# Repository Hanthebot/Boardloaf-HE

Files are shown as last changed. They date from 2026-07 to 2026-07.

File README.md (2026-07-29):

# Boardloaf-HE

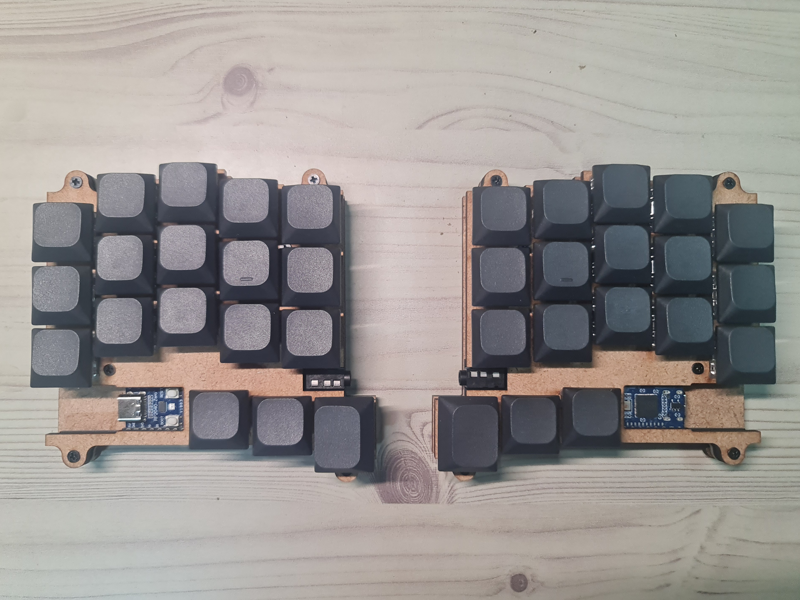
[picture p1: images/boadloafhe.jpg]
boardloafhe


Hall-effect variant of [Yuburoll's Boardloaf](https://github.com/yuburoll/Boardloaf), a 36-key split keyboard.

Wooting compatible, reversible, under 100mm pcb with qmk/vial support.

Based on Boardloaf and strongly inspired by [TrueStrike42](https://github.com/byungyoonc/TrueStrike42)

## Preparation
- Pricing: PCB based on JLCPCB / components based on Taobao (shipping to South Korea)
- Shipping fee not included, but PCB can be shipped with $1.5 option and Taobao delivery fee is acceptable for price gap
- Assumes you only want to build one (which makes cost higher)

### Board
| Component | Qty | Price/unit | Price |
| --- | --- | --- | ----- |
| PCB | 2 | $2/5 pcs | $2 |
| SOT-23 SS49E | 36  | ¥0.31/1 pc ~= $0.05 | $2 |
| SOIC-16 74HC4051(D)  | 6 | ¥0.74/1 pc ~= $0.11 | $0.7  |
| 0805 0.1uf capacitor | 42  | ¥2.5/50 pcs ~= $0.4 | $0.4  |
| PJ320A TRRS socket | 2 | ¥8/100 pcs ~= $1.2  | $1.2  |
| RP2040 Zero | 2 | ¥7.3/1 pc ~= $1.1 | $2.2  |
- For capacitor, 0.1~1uf should be fine
- And obviously, USB-C cable of your choice (with machine) and TRS/TRRS cable of your choice
- Board cost: $9 or more

### Case
- Option A: 3D printed case (from yuburoll's repo)
- Option B: Cheap plate cut
  - requires heat insert and standoff
  - 3T mdf panel of A4 size can fit 2x top & bottom plate
      - and costs about $1

| Component | Qty | Price/unit | Price |
| --- | --- | --- | ----- |
| M2 screw 6mm | 16  | ¥4/500 pcs ~= $0.6 | $0.6  |
| M2 heat insert 3*3 | 16  | ¥4.9/100 pcs ~= $0.7  | $0.7  |
| M2 standoff 7mm + 3mm head | 16  | ¥2.31/50 pcs ~= $0.35 | $0.35 |
- Flathead screw was used
- Standoff can be shorter or longer - but I recommend 5mm at least
- Case cost: $3 or more

### Switches
| Component | Qty | Price/unit | Price |
| --- | --- | --- | ----- |
| Wooting compatible magnetic switch | 36  | ¥36/40 pcs ~= $5.3 | $5.3  |
- I personally chose Everglide Sticky Rice, as it was the cheapest I could find.
- While those without side pins should be fine, I'd use one with side pins so that they fix better
- Firmware fix may be required to use the opposite polarity
- Switch cost: $6 or more

With these things combined, you can get your own HE keyboard in about $12 excluding cables and switches.

## [Build guide](GUIDE.md)

## Features
- Supports both APC and rapid trigger
- Cheap, simple, and working
- 3 multiplexor on each side, scanning 6 keys per mux

## Improvements to be done
- [ ] Support analog mousekey
- [ ] Switch to full duplex / TRRS communication
- [x] Make SOT-23 pad larger, thus easier to solder
- [ ] ~~Switch to blackpill mcu for better ADC (not in this repo)~~

## Remarks
- Initial config recommendation: 30% / 20% / 20% / 10% / 10% / 20% (APC act / release; RT init dead / act offset / release offset / bottom dead)
- Documentation
  - Further documentation in progress
  - Plate KiCad file to be uploaded
  - Images to be added
- Case
  - PCB outline and holes are the same as original Boardloaf, thus all housing are compatible
  - I used cheap 3T mdf for housing, with bumpons. Works fine for me
- Random
  - PCB schematics are almost directly from TrueStrike42
  - If your board does not work, it's likely soldering issue. Try cleaning the board well and solder again
  - I think it's a good start on implementing random idea for HE keyboard

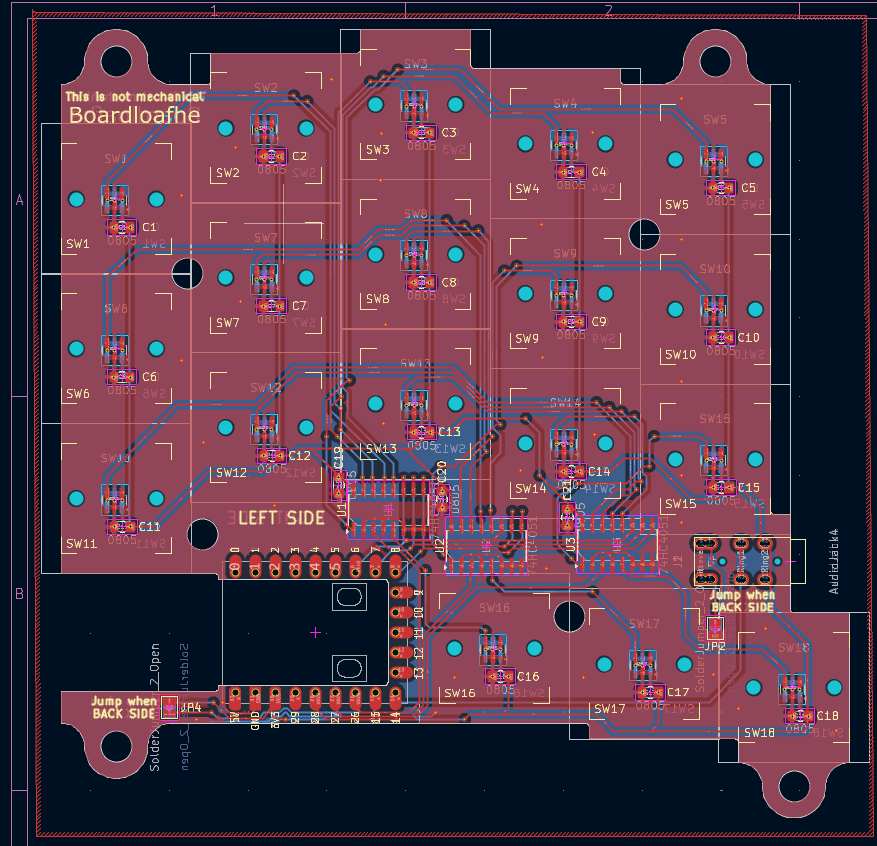
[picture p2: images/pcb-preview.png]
PCB


## Licenses
All code under firmware folder follows GPL v3.

Webapp is MIT license.

CC BY-SA 4.0 license for all hardware / design: inherited from Boardloaf

## Disclaimer
Webapp and firmware modification were vibe coded.
I checked it working.

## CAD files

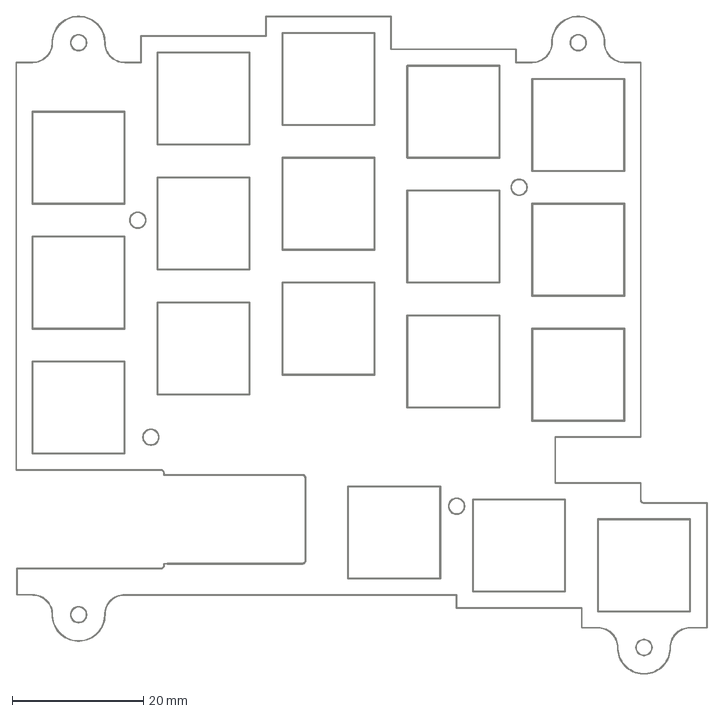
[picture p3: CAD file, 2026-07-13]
plate/top-plate.dxf
105.1 x 100.1 mm

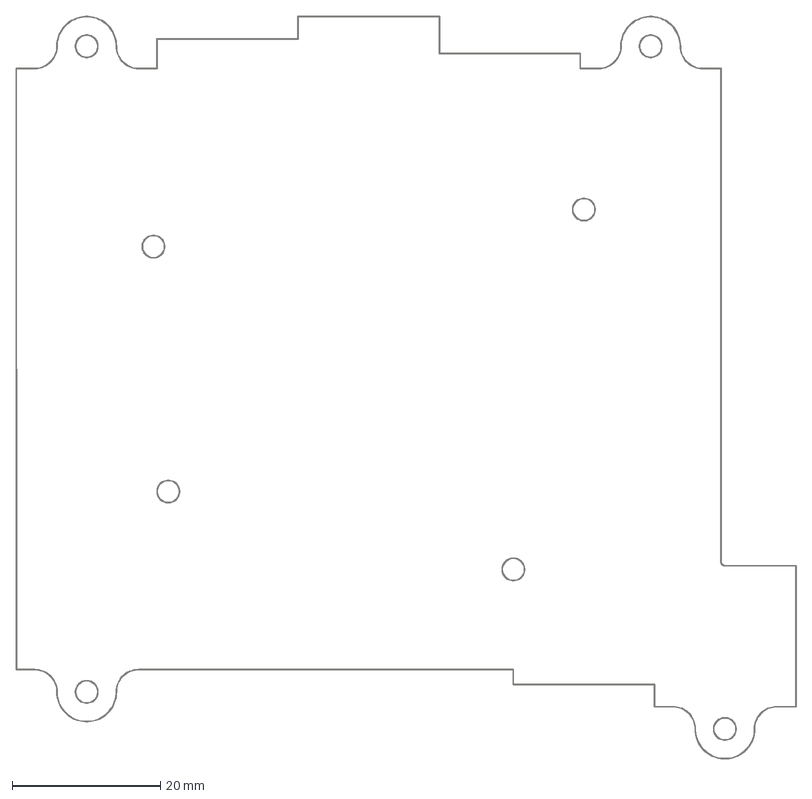
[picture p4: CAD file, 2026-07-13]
plate/bottom-plate.dxf
105.1 x 100.1 mm

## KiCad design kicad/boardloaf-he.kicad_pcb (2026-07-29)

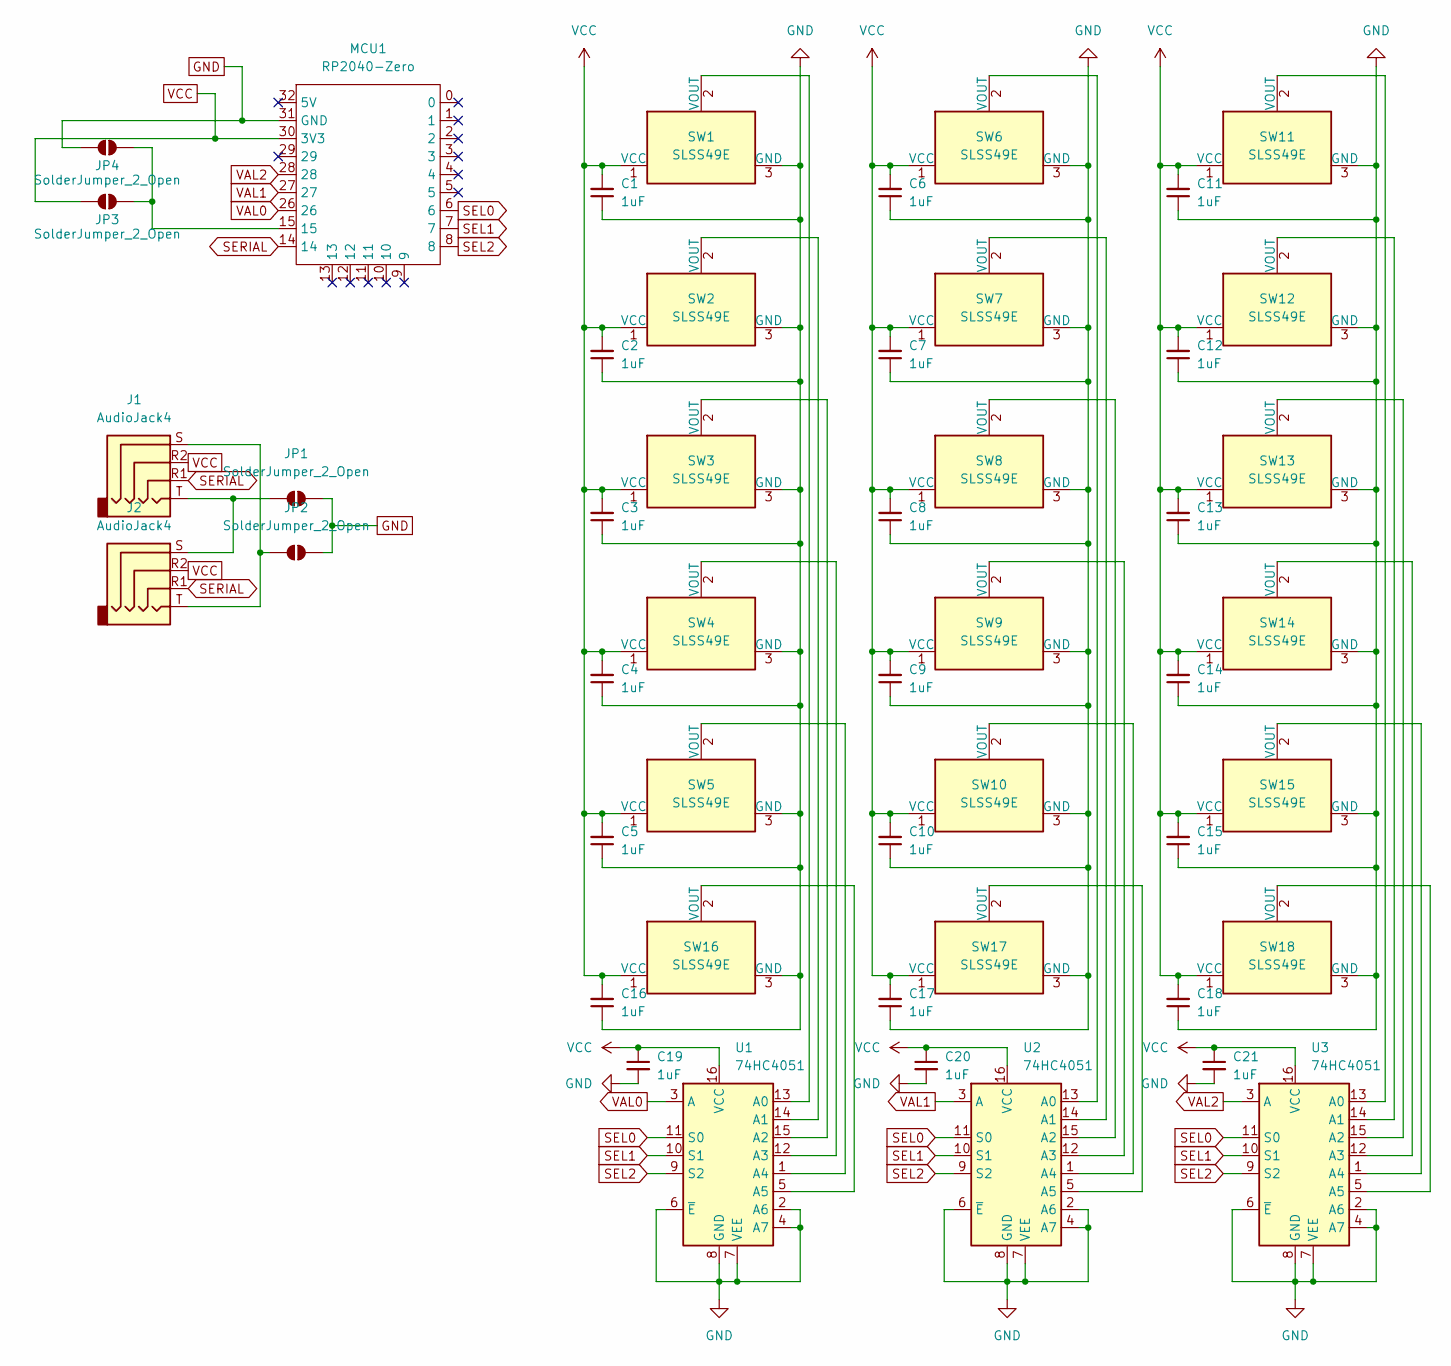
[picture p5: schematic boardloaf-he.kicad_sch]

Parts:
C1, C2, C3, C4, C5, C6, C7, C8, C9, C10, C11, C12, C13, C14, C15, C16, C17, C18, C19, C20, C21: 1uF; C_0805_2012Metric_Pad1.18x1.45mm_HandSolder
J1, J2: AudioJack4; TRRS-PJ-320A_PIN
JP1, JP2, JP3, JP4: SolderJumper_2_Open; SolderJumper-2_P1.3mm_Open_TrianglePad1.0x1.5mm
MCU1: RP2040-Zero; RP2040-Zero-RESIZED
SW1, SW2, SW3, SW4, SW5, SW6, SW7, SW8, SW9, SW10, SW11, SW12, SW13, SW14, SW15, SW16, SW17, SW18: SLSS49E; HE-Switch-1U
U1, U2, U3: 74HC4051; SOIC-16_3.9x9.9mm_P1.27mm

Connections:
GND: C1.1, C2.1, C3.1, C4.1, C5.1, C6.1, C7.1, C8.1, C9.1, C10.1, C11.1, C12.1, C13.1, C14.1, C15.1, C16.1, C17.1, C18.1, C19.2, C20.2, C21.2, JP1.2 (B), JP2.2 (B), JP4.1 (A), MCU1.31 (GND), SW1.3 (GND), SW2.3 (GND), SW3.3 (GND), SW4.3 (GND), SW5.3 (GND), SW6.3 (GND), SW7.3 (GND), SW8.3 (GND), SW9.3 (GND), SW10.3 (GND), SW11.3 (GND), SW12.3 (GND), SW13.3 (GND), SW14.3 (GND), SW15.3 (GND), SW16.3 (GND), SW17.3 (GND), SW18.3 (GND), U1.2 (A6), U1.4 (A7), U1.6 (~E), U1.7 (VEE), U1.8 (GND), U2.2 (A6), U2.4 (A7), U2.6 (~E), U2.7 (VEE), U2.8 (GND), U3.2 (A6), U3.4 (A7), U3.6 (~E), U3.7 (VEE), U3.8 (GND)
unnamed: J1.T, J2.S, JP1.1 (A)
unnamed: J1.S, J2.T, JP2.1 (A)
unnamed: JP3.2 (B), JP4.2 (B), MCU1.15
unnamed: SW1.2 (VOUT), U1.13 (A0)
unnamed: SW2.2 (VOUT), U1.14 (A1)
unnamed: SW3.2 (VOUT), U1.15 (A2)
unnamed: SW4.2 (VOUT), U1.12 (A3)
unnamed: SW5.2 (VOUT), U1.1 (A4)
unnamed: SW6.2 (VOUT), U2.13 (A0)
unnamed: SW7.2 (VOUT), U2.14 (A1)
unnamed: SW8.2 (VOUT), U2.15 (A2)
unnamed: SW9.2 (VOUT), U2.12 (A3)
unnamed: SW10.2 (VOUT), U2.1 (A4)
unnamed: SW11.2 (VOUT), U3.13 (A0)
unnamed: SW12.2 (VOUT), U3.14 (A1)
unnamed: SW13.2 (VOUT), U3.15 (A2)
unnamed: SW14.2 (VOUT), U3.12 (A3)
unnamed: SW15.2 (VOUT), U3.1 (A4)
unnamed: SW16.2 (VOUT), U1.5 (A5)
unnamed: SW17.2 (VOUT), U2.5 (A5)
unnamed: SW18.2 (VOUT), U3.5 (A5)
SEL0: MCU1.6, U1.11 (S0), U2.11 (S0), U3.11 (S0)
SEL1: MCU1.7, U1.10 (S1), U2.10 (S1), U3.10 (S1)
SEL2: MCU1.8, U1.9 (S2), U2.9 (S2), U3.9 (S2)
SERIAL: J1.R1, J2.R1, MCU1.14
VAL0: MCU1.26, U1.3 (A)
VAL1: MCU1.27, U2.3 (A)
VAL2: MCU1.28, U3.3 (A)
VCC: C1.2, C2.2, C3.2, C4.2, C5.2, C6.2, C7.2, C8.2, C9.2, C10.2, C11.2, C12.2, C13.2, C14.2, C15.2, C16.2, C17.2, C18.2, C19.1, C20.1, C21.1, J1.R2, J2.R2, JP3.1 (A), MCU1.30 (3V3), SW1.1 (VCC), SW2.1 (VCC), SW3.1 (VCC), SW4.1 (VCC), SW5.1 (VCC), SW6.1 (VCC), SW7.1 (VCC), SW8.1 (VCC), SW9.1 (VCC), SW10.1 (VCC), SW11.1 (VCC), SW12.1 (VCC), SW13.1 (VCC), SW14.1 (VCC), SW15.1 (VCC), SW16.1 (VCC), SW17.1 (VCC), SW18.1 (VCC), U1.16 (VCC), U2.16 (VCC), U3.16 (VCC)

Board: 2 copper layers, 49 parts (3 on the bottom side), 30 nets, no tracks yet.

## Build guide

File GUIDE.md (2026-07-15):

# Build guide

Also check out: [Modubu build guide](https://github.com/yuburoll/modubu/blob/main/documents/buildGuide_ko.md) (RP2040 Zero soldering, in Korean)

### Preparation
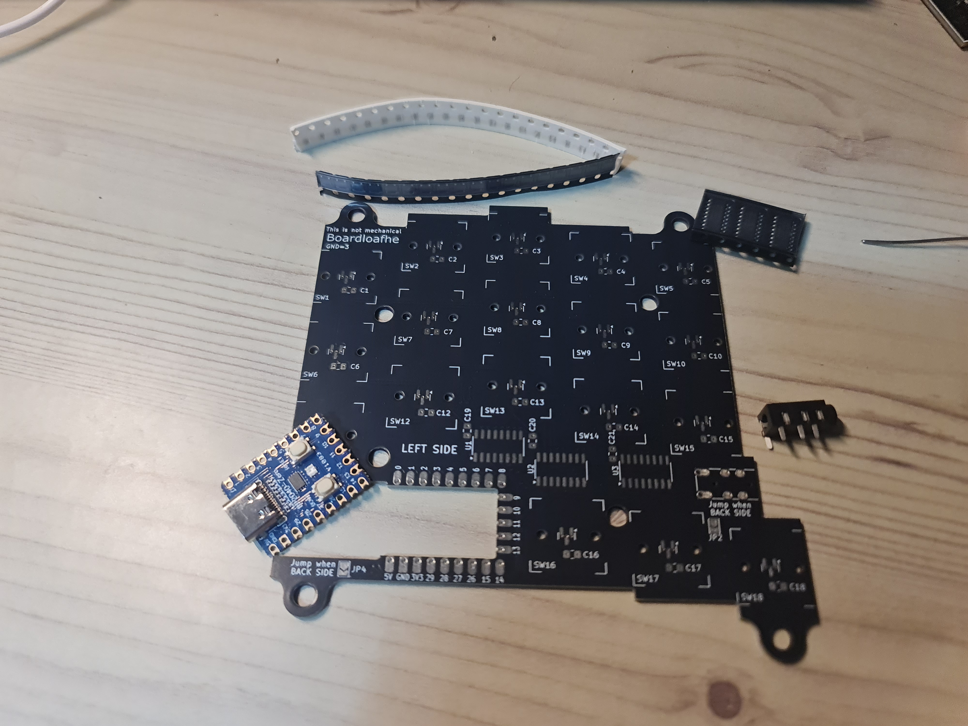
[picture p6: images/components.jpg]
Components


For each half, make sure you have:
- PCB
- RP2040 Zero
- PJ320A TRRS 3.5mm Socket
- SOIC-16 74HC4051 x 3
- SOT-23 SS49E x 36
- 0805 0.1uf capacitor x 42
  - actually optional

Recommended soldering order:
1. 74HC4051
2. SS49E
3. RP2040 Zero
4. PJ320A
5. capacitor

All jumpers: at the back

### 74HC4051
Ensure that the circle mark matches the arrow mark on the PCB!
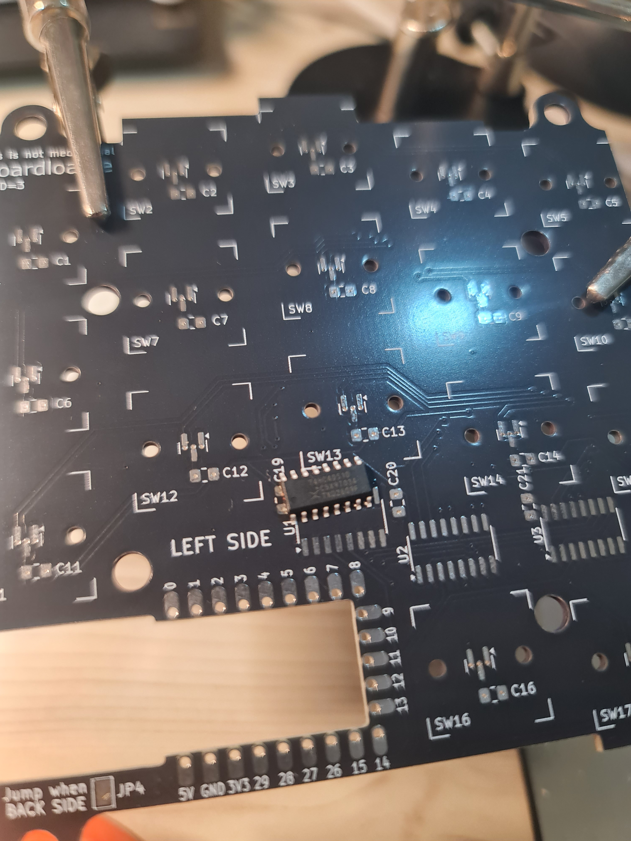
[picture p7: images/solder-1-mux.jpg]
mux-solder-1


As many build guides suggested, apply solder on one of the solder mask, then push the component towards solder while it's molten.

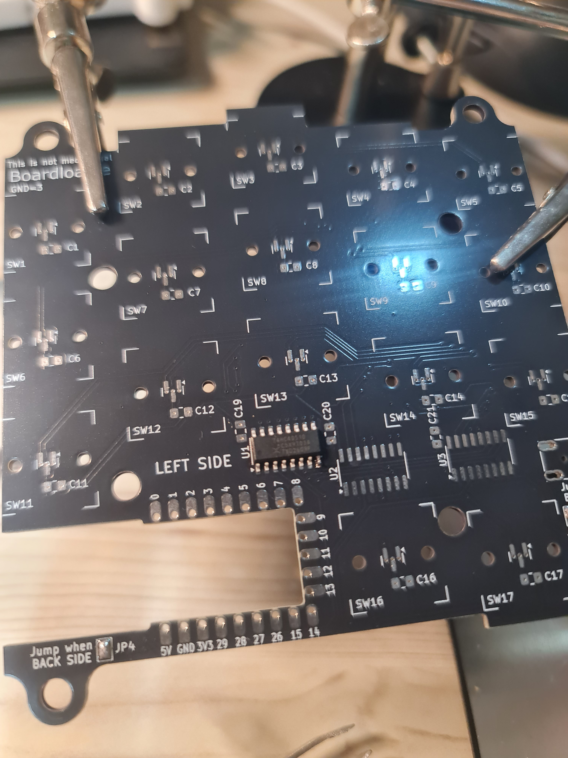
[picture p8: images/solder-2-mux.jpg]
mux-solder-2


Then you may solder the rest. PCB is reversible, but the multiplexor can only lie on single plane.

### SS49E

Like the multiplexor, apply solder on one of the solder mask - I recommend the middle one. Push it, and finish soldering other pins. Just in case, ensure that your sensor has the same pinout as PCB! (it probably will).

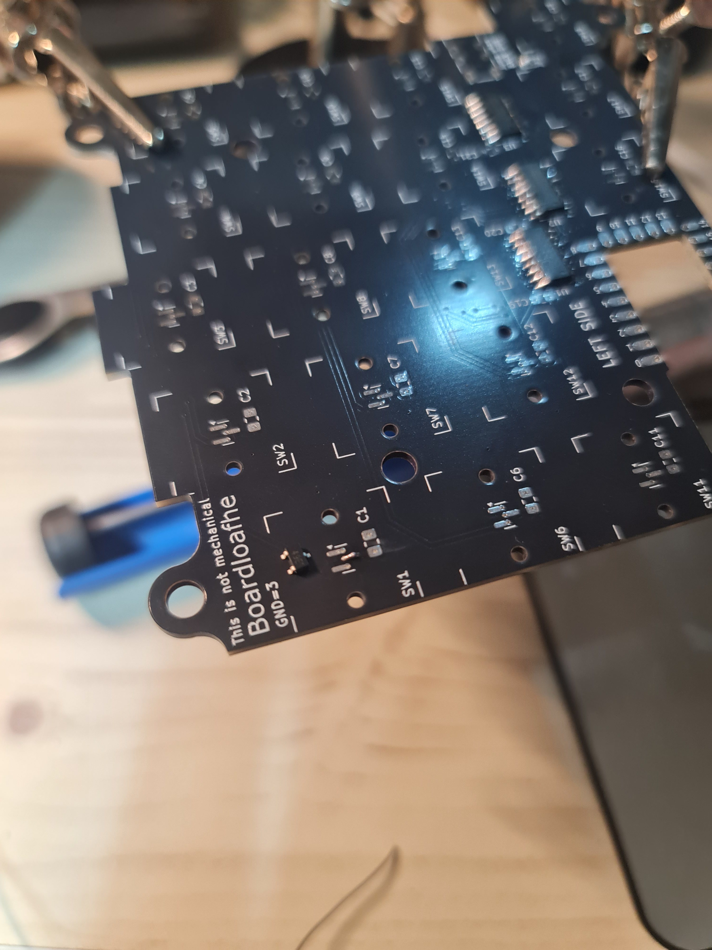
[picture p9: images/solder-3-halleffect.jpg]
halleffect-solder


### RP2040 Zero
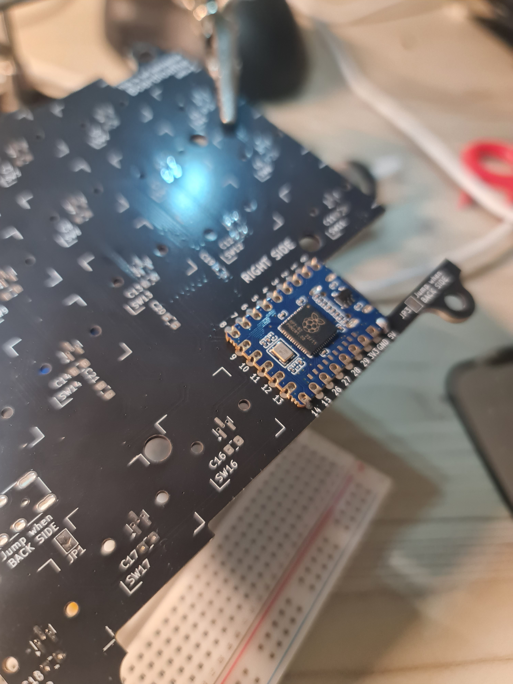
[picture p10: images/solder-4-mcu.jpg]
MCU

Solder in SMD manner, ensuure that the pin number matches the PCB.

USB-C port will be almost on the same plane with the PCB.

Recommendataion: solder one corner or more. Then solder the rest.

### PJ320A
*Just do it*

### Capacitor

Capacitors are to prevent voltage shocks... or so I heard. The keyboard should work properly without it, but let's play safe.

It has no direction.

Like others, apply solder, push, and pull.

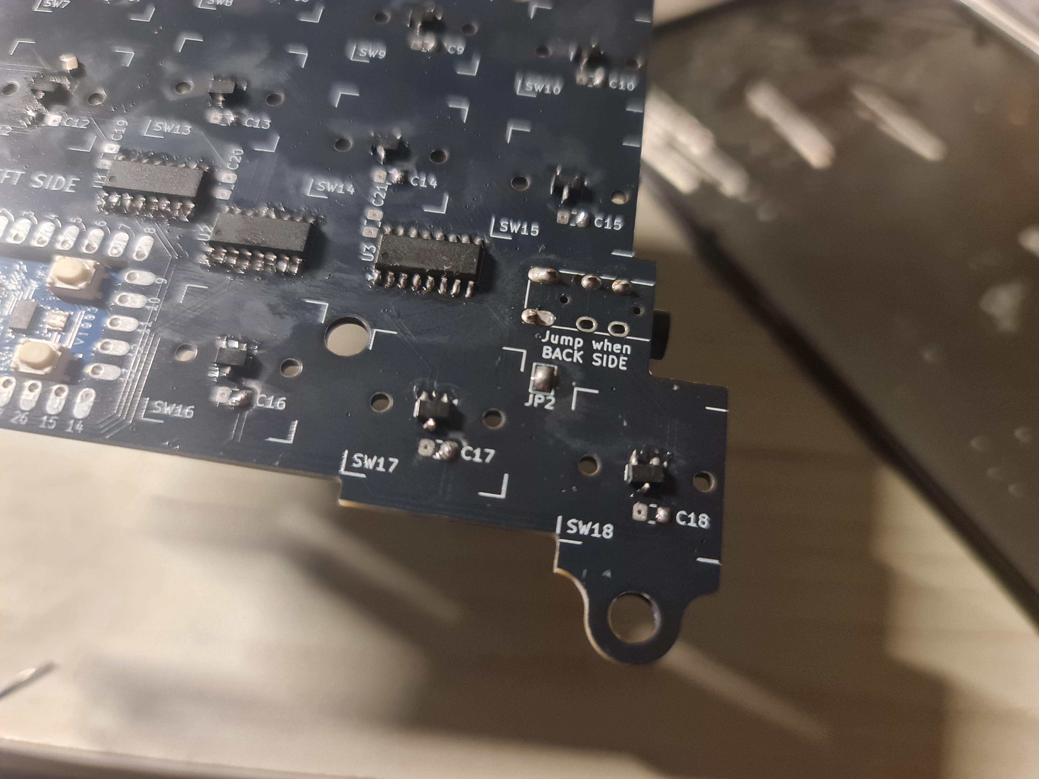
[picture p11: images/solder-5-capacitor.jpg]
capacitor-solder-1


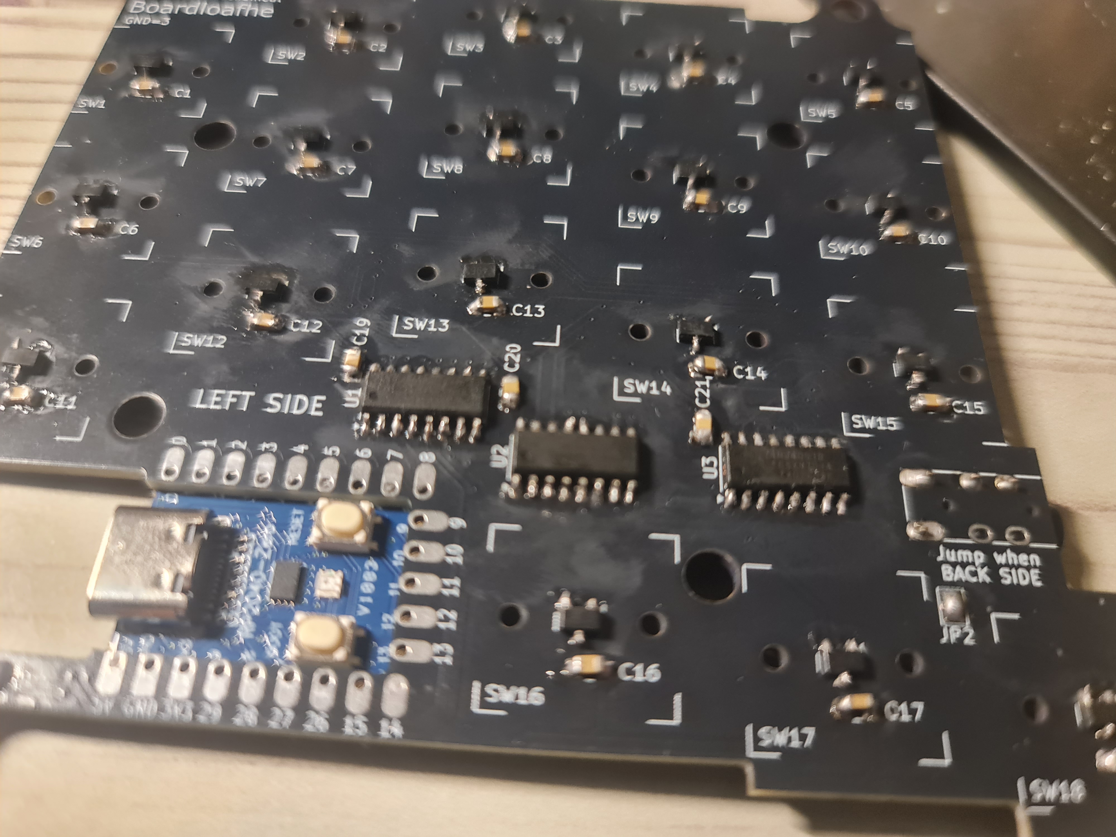
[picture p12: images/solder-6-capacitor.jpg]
capacitor-solder-2


### Complete
Then it looks like this.
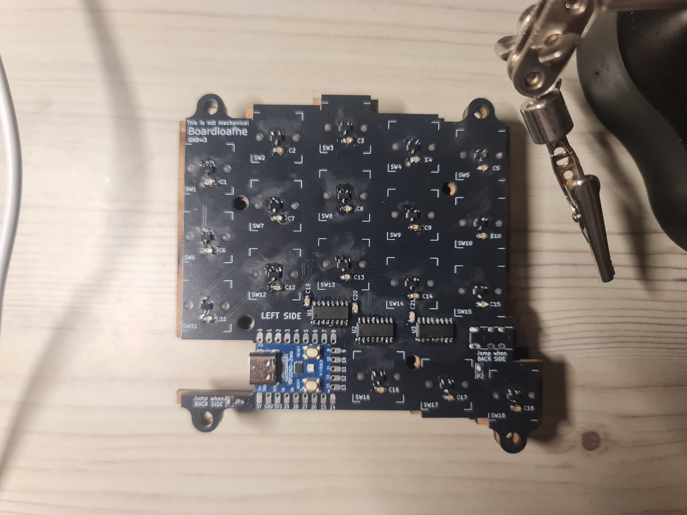
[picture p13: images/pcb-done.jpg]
PCB-Done


Left is mdf sandwich version, and right is Yuburoll's original Boardloaf, with 3d printed case.
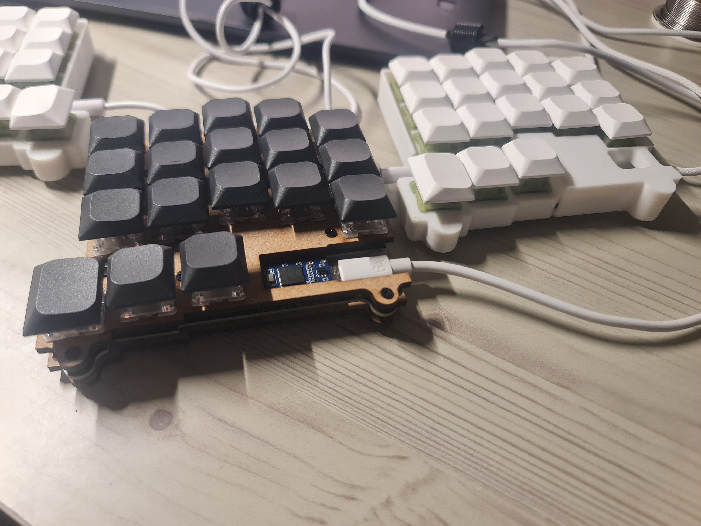
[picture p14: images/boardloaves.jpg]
Boardloaves


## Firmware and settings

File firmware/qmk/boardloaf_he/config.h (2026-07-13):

#pragma once

#define HE_MATRIX_ROWS 3 // Rows per half
#define MATRIX_COLS 6 // Columns per half

#define MATRIX_ROW_PINS \
    { GP26, GP27, GP28 }

#define ROWS_PER_COL \
    { 3, 3, 3, 3, 3, 3 }

#define AMUX_MAX_COLS_COUNT 6

#define AMUX_SEL_PINS \
    { GP6, GP7, GP8 }

#define AMUX_COL_CHANNELS \
    { 0, 1, 2, 3, 4, 5 }

#define DEFAULT_ACTUATION_MODE 0
// "Light" preset based on 480-330 sensor range (~150 counts travel):
// APC actuation at 30% travel, release at 20% travel (10% hysteresis)
// RT deadzone at 30%, act offset ~10 counts (6.7% of travel), rel offset ~8 counts (5.3%)
#define DEFAULT_MODE_0_ACTUATION_LEVEL 300
#define DEFAULT_MODE_0_RELEASE_LEVEL 200
#define DEFAULT_MODE_1_INITIAL_DEADZONE_OFFSET 300
#define DEFAULT_MODE_1_ACTUATION_OFFSET 10
#define DEFAULT_MODE_1_RELEASE_OFFSET 8
#define DEFAULT_BOTTOM_DEADZONE 50
#define DEFAULT_EXTREMUM 1023
#define NOISE_CEILING_THRESHOLD 30
#define BOTTOMING_CALIBRATION_THRESHOLD 50
#define DEFAULT_NOISE_CEILING_SAMPLING_COUNT 30
#define DEFAULT_BOTTOMING_READING 0
#define DEFAULT_CALIBRATION_STARTER true

#define EECONFIG_KB_DATA_SIZE 217

#define VIA_CUSTOM_LIGHTING_ENABLE

#define WEAK_BITRATE

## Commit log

2026-07-13 Minimum Viable Documentation & File
    [boardloaf-he-B_Adhesive.gbr, boardloaf-he-B_Courtyard.gbr, boardloaf-he-B_Cu.gbr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]
2026-07-13 Plates dxf and Images
    [bottom-plate.dxf, top-plate.dxf]
2026-07-13 Updated standoff info
2026-07-26 Typo fix
    [boardloaf-he-B_Adhesive.gbr, boardloaf-he-B_Courtyard.gbr, boardloaf-he-B_Cu.gbr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]
2026-07-29 Footprint update - larger SOT23, silkscreen on the back
    [boardloaf-he-B_Adhesive.gbr, boardloaf-he-B_Courtyard.gbr, boardloaf-he-B_Cu.gbr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]
2026-07-29 Made schematic sync with PCB
    [boardloaf-he-B_Adhesive.gbr, boardloaf-he-B_Courtyard.gbr, boardloaf-he-B_Cu.gbr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]
2026-07-29 Updated gerber.zip
